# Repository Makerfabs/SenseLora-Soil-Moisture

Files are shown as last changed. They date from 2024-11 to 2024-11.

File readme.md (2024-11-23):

SenseLora Soil Moisture
```c++
/*
Version:	    V1.0
Author:		    Yuki
Create Date:	2024/11/20
Note:
*/
```

# Makerfabs

[Makerfabs home page](https://www.makerfabs.com/)

[Makerfabs Wiki](https://wiki.makerfabs.com/)

## Intruduce

Product Link:[SenseLora Soil Moisture](https://www.makerfabs.com/senselora-soil-moisture.html)

Wiki Link : [SenseLora Soil Moisture](https://wiki.makerfabs.com/SenseLora_Soil_Moisture.html)

## Features

Specs:
- ESP32-S3 WROOM module onboard with the WiFi and Bluetooth.
- Detection of soil moisture.
- Arduino Compatible: You can play it with Arduino IDE.
- Onboard LoRa module (433Mhz or 868Mhz or 915Mhz)
- Completely sealed.
- Dustproof waterproof level:IP68.
- Power by 3.7V battery.
- On board MPTT battery charger by solar panel.

# Usage

1.[Usage with LoRa Receiver](https://wiki.makerfabs.com/SenseLora_Soil_Moisture.html#4-usage-with-lora-receiver)

The Lora receiver work with SenseLora modules, it receive LoRa signal around and forward to computer, so the data can be display/record/analyze on PC.

2.[Usage with 4G Gateway](https://wiki.makerfabs.com/SenseLora_Soil_Moisture.html#5-usage-with-4g-gateway)

The 4G LTE CAT1 Gateway work with SenseLora modules, it get the LoRa data and then transmit the data via 4G to cloud server such as TTN, or the monitors phone with SMS.  

## Example

### firmware

Factory test program

### Send data to datacake

Using the Senselora 4G gateway to transfer data to the datacake platform.

### Send data to thingspeak

Using the Senselora 4G gateway to transfer data to the thingspeak platform.

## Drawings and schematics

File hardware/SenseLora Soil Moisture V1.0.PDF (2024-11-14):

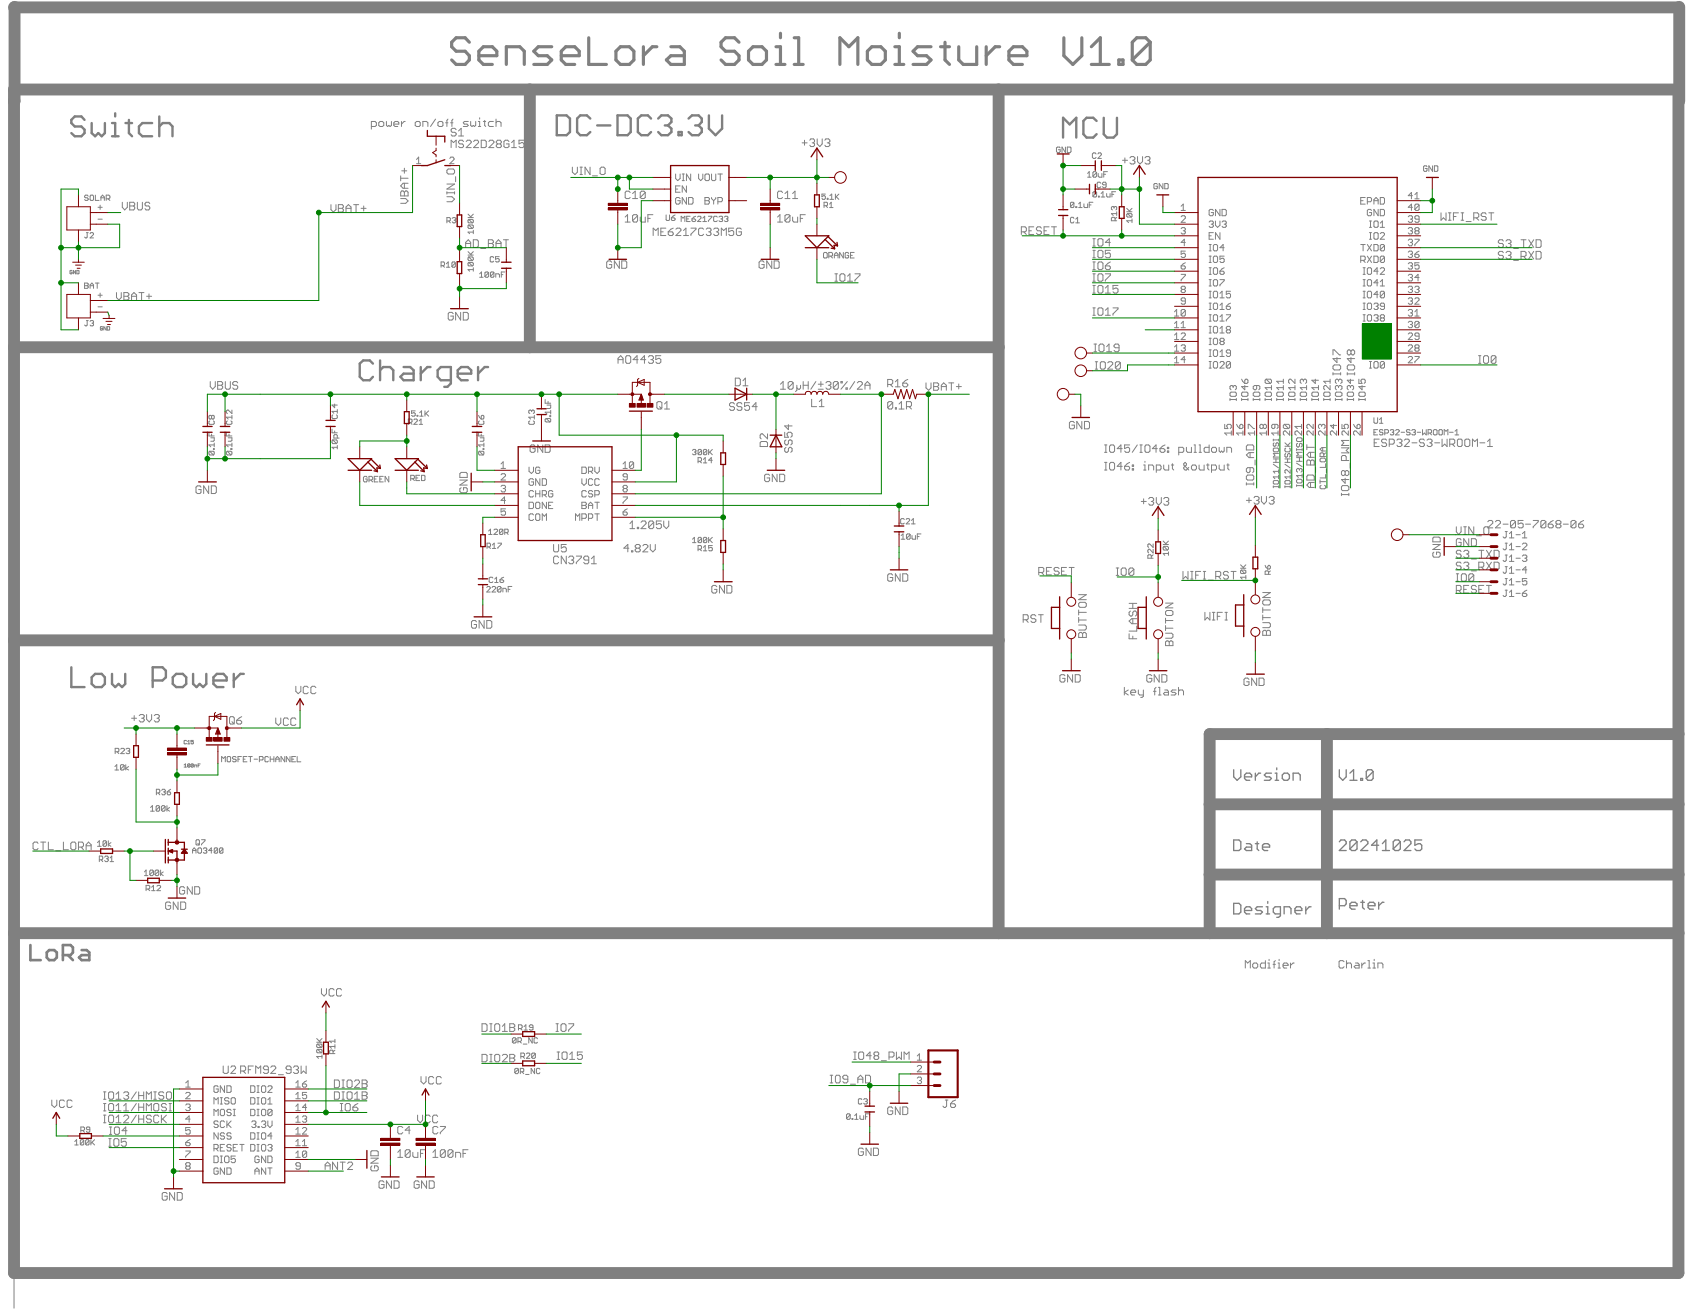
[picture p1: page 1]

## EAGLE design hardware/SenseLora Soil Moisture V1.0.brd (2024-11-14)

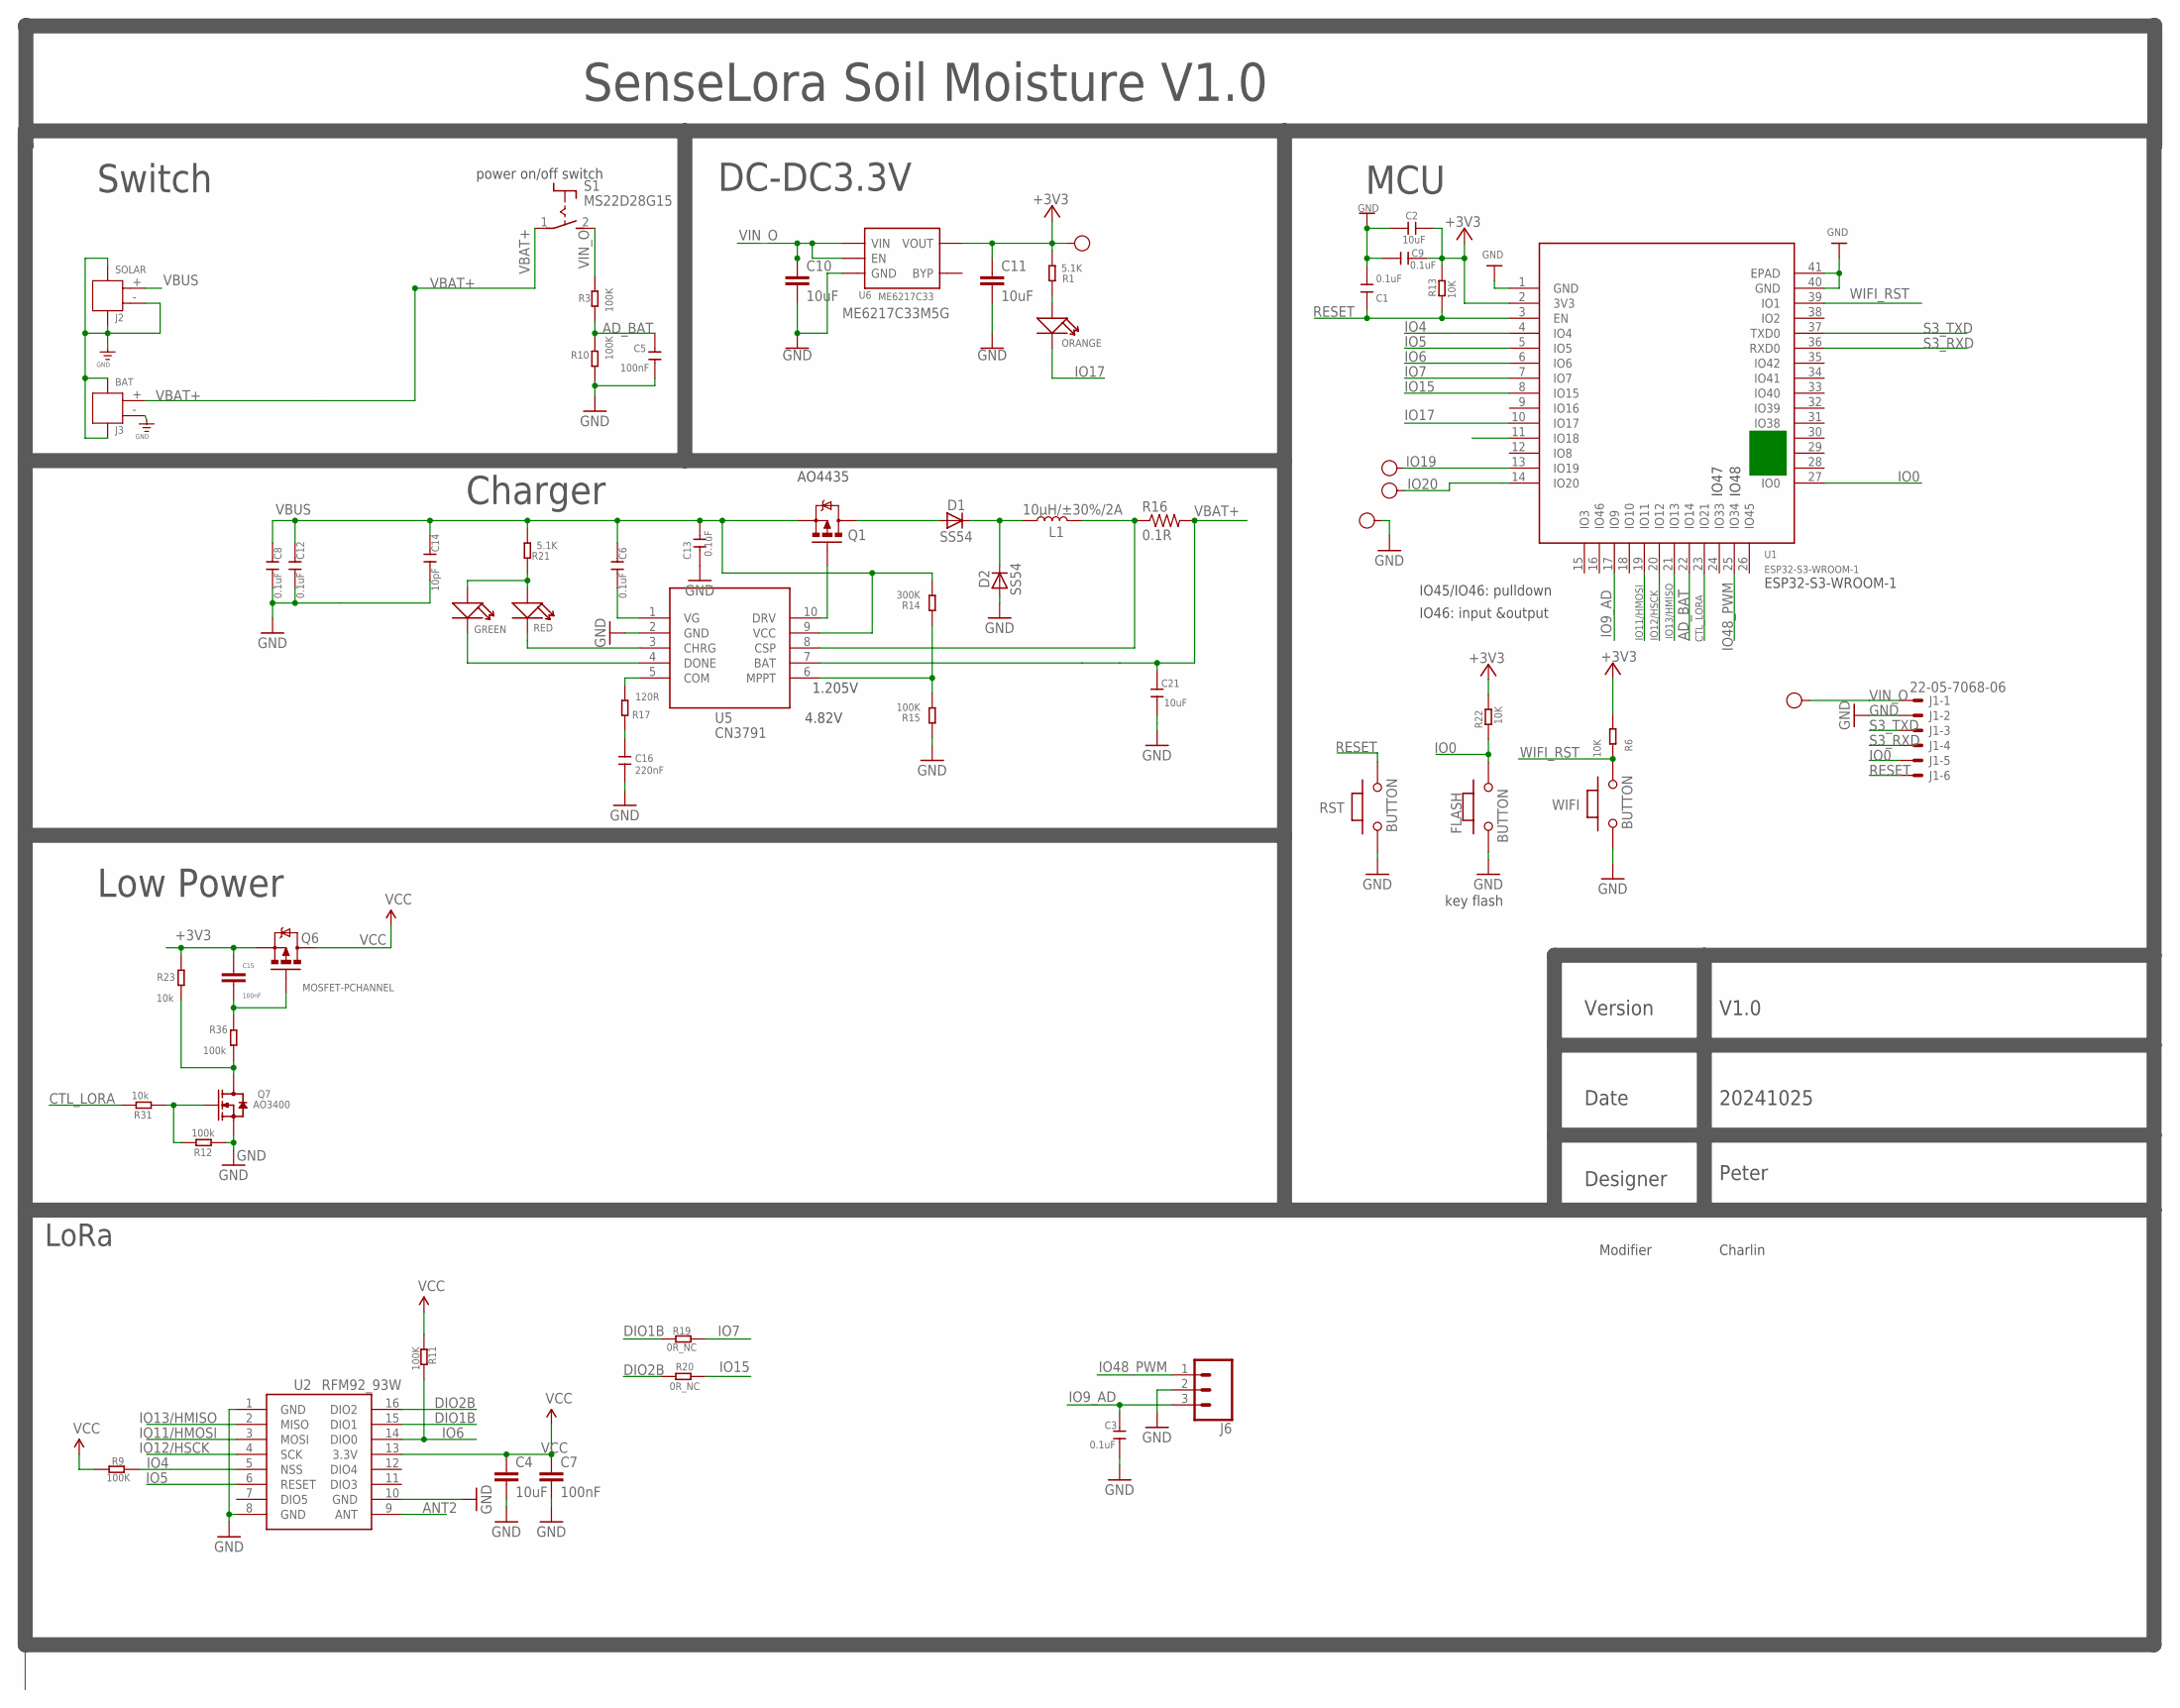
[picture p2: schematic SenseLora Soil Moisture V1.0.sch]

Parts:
3V3: TEST-POINT'4545'; TP-D45MIL; PARTNO DNP
C1, C3, C6, C8, C9, C12, C13: 0.1uF; DISCRETE_C0603
C2, C21: 10uF; DISCRETE_C0603
C4, C10, C11: 10uF; C0603
C5, C7, C15: 100nF; C0603
C14: 10pF; DISCRETE_C0603
C16: 220nF; DISCRETE_C0603
CHRG: RED; LED-0603
D1, D2: SS54; DO-214AC
D+: TEST-POINT'4545'; TP-D45MIL; PARTNO DNP
D-: TEST-POINT'4545'; TP-D45MIL; PARTNO DNP
DONE: GREEN; LED-0603
FLASH: BUTTON; 157SW
GND: TEST-POINT'4545'; TP-D45MIL; PARTNO DNP
J1: 22-05-7068-06; 7395-06
J2: SOLAR; HW2-SMD-2.0-90D
J3: BAT; HW2-SMD-2.0-90D
J6: CONN_03SCREW; SCREWTERMINAL-3.5MM-3
L1: 10µH/±30%/2A; CR54
Q1: MOSFET-PCHANNELFDS6675; SO08
Q6: MOSFET-PCHANNEL; SOT23-3
Q7: AO3400; SOT23@1
R1, R21: 5.1K; DISCRETE_R0603
R3, R9, R10, R11: 100K; R0603
R6, R13, R22: 10K; R0603
R12, R36: 100k; R0603
R14: 300K; DISCRETE_R0603
R15: 100K; DISCRETE_R0603
R16: 0.1R; R1206
R17: 120R; DISCRETE_R0603
R19, R20: 0R_NC; R0603
R23, R31: 10k; R0603
RST: BUTTON; 157SW
S1: MS22D28G15; S-MS22D28G15
STA: ORANGE; LED-0603
U1: ESP32-S3-WROOM-1; ESP32-­S2-­SOLO
U2: RFM92_93W
U5: CN3791; SSOP-10-150MIL
U6: ME6217C33; SOT23-5
VI: HP; TP-D45MIL; PARTNO DNP
WIFI: BUTTON; 157SW

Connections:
+3V3: 3V3.T, C2.1, C9.1, C11.1, C15.1, Q6.2 (S), R1.2, R6.2, R13.2, R22.2, R23.2, U1.2 (3V3), U6.5 (VOUT)
AD_BAT: C5.1, R3.2, R10.1, U1.22 (IO14)
ANT2: U2.9 (ANT)
CTL_LORA: R31.2, U1.23 (IO21)
DIO1B: R19.2, U2.15 (DIO1)
DIO2B: R20.2, U2.16 (DIO2)
GND: C1.2, C2.2, C3.2, C4.2, C5.2, C7.2, C8.2, C9.2, C10.2, C11.2, C12.2, C13.1, C14.2, C16.2, C21.2, D2.A, FLASH.1, GND.T, J1.2, J2.3, J2.4, J2.- (2), J3.3, J3.4, J3.- (2), J6.2, Q7.2 (S), R10.2, R12.1, R15.1, RST.1, U1.1 (GND), U1.40 (GND), U1.41 (EPAD), U2.1 (GND), U2.8 (GND), U2.10 (GND), U5.2 (GND), U6.2 (GND), WIFI.1
IO0: FLASH.2, J1.5, R22.1, U1.27 (IO0)
IO4: R9.1, U1.4 (IO4), U2.5 (NSS)
IO5: U1.5 (IO5), U2.6 (RESET)
IO6: R11.1, U1.6 (IO6), U2.14 (DIO0)
IO7: R19.1, U1.7 (IO7)
IO9_AD: C3.1, J6.3, U1.17 (IO9)
IO11/HMOSI: U1.19 (IO11), U2.3 (MOSI)
IO12/HSCK: U1.20 (IO12), U2.4 (SCK)
IO13/HMISO: U1.21 (IO13), U2.2 (MISO)
IO15: R20.1, U1.8 (IO15)
IO17: STA.-, U1.10 (IO17)
IO19: D-.T, U1.13 (IO19)
IO20: D+.T, U1.14 (IO20)
IO48_PWM: J6.1, U1.25 (IO34)
unnamed: R14.1, R15.2, U5.6 (MPPT)
unnamed: Q1.4 (G), U5.10 (DRV)
unnamed: C6.2, U5.1 (VG)
unnamed: D1.C, D2.C, L1.P$1 (1)
unnamed: D1.A, Q1.5 (D), Q1.6 (D), Q1.7 (D), Q1.8 (D)
unnamed: CHRG.+, DONE.+, R21.1
unnamed: DONE.-, U5.4 (DONE)
unnamed: CHRG.-, U5.3 (CHRG)
unnamed: R17.2, U5.5 (COM)
unnamed: C16.1, R17.1
unnamed: R1.1, STA.+
unnamed: C15.2, Q6.1 (G), R36.2
unnamed: Q7.1 (G), R12.2, R31.1
unnamed: L1.P$2 (2), R16.1, U5.8 (CSP)
unnamed: Q7.3 (D), R23.1, R36.1
RESET: C1.1, J1.6, R13.1, RST.2, U1.3 (EN)
S3_RXD: J1.4, U1.36 (RXD0)
S3_TXD: J1.3, U1.37 (TXD0)
VBAT+: C21.1, J3.+ (1), R16.2, S1.1, U5.7 (BAT)
VBUS: C6.1, C8.1, C12.1, C13.2, C14.1, J2.+ (1), Q1.1 (S), Q1.2 (S), Q1.3 (S), R14.2, R21.2, U5.9 (VCC)
VCC: C4.1, C7.1, Q6.3 (D), R9.2, R11.2, U2.13 (3.3V)
VIN_O: C10.1, J1.1, R3.1, S1.2 (S), U6.1 (VIN), U6.3 (EN), VI.T
WIFI_RST: R6.1, U1.39 (IO1), WIFI.2

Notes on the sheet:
DC-DC3.3V
ME6217C33M5G
Charger
LoRa
power on/off switch
key flash
Switch
MCU
Low Power
IO45/IO46: pulldown
IO46: input &output
ESP32-S3-WROOM-1
IO47
IO48
Version
Date
Designer
V1.0
20241025
Peter
SenseLora Soil Moisture V1.0
1.205V
4.82V
Modifier
Charlin
AO4435

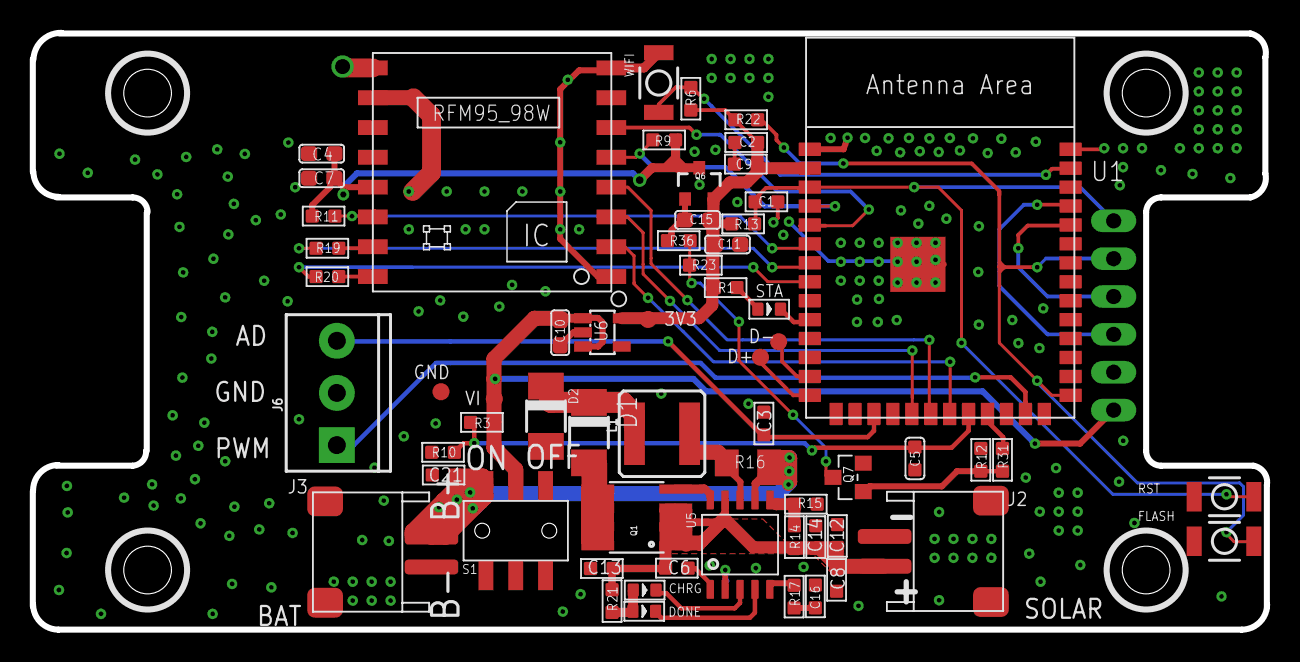
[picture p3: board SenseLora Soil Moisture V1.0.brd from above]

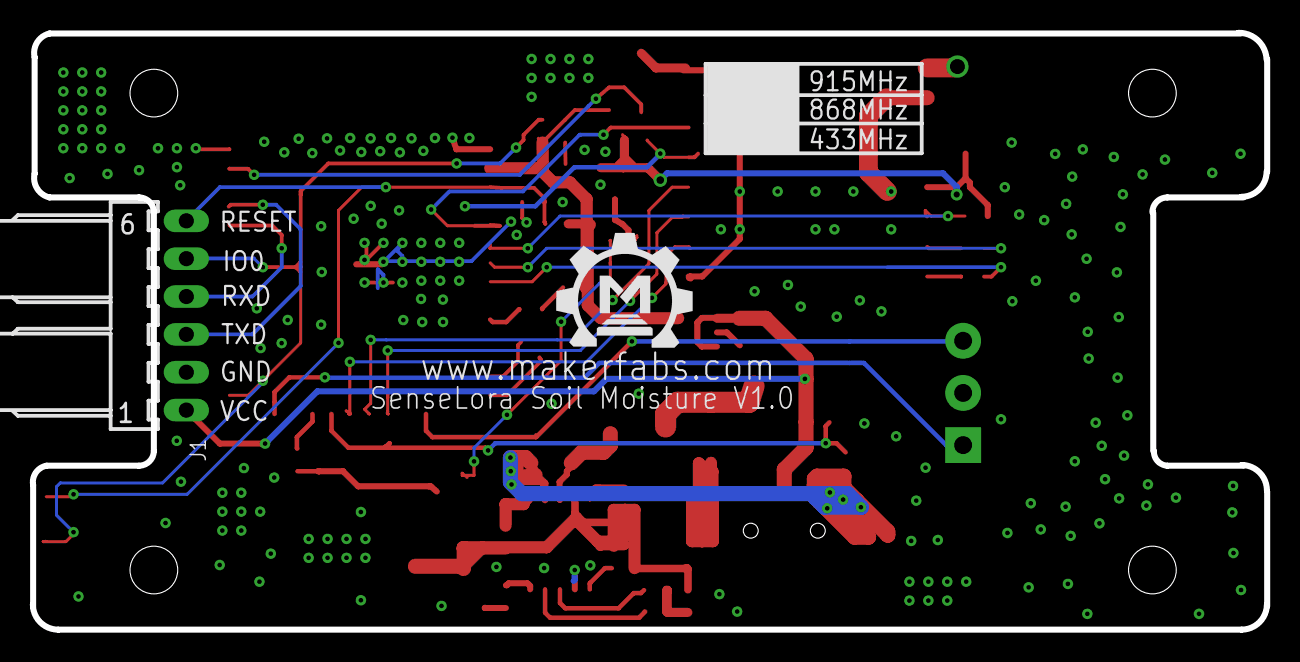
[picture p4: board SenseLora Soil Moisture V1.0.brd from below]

Board: 2 copper layers, 82.8 x 40.0 mm, 63 parts (2 on the bottom side), 43 nets.

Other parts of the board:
U$3: MAKERFABS_0.3

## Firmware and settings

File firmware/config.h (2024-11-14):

#ifndef CONFIG_H
#define CONFIG_H

#define AP_SSID "Makerfabs-"
#define AP_PWD "12345678"

#define DEFAULT_SENSOR_ID "SoilM01"
#define DEFAULT_SLEEP_TIME "3600"

#define SUCCESS 1
#define ERROR 0

#define NVS_DATA_LENGTH 20

#define uS_TO_S_FACTOR 1000000ULL /* Conversion factor for micro seconds to seconds */

#define BUTTON_PIN 1
#define BAT_PIN 14

// Lora
#define LORA_RST 5
#define LORA_CS 4

#define DIO0 6
#define DIO1 7

#define SPI_MOSI 11
#define SPI_MISO 13
#define SPI_SCK 12

#define FREQUENCY 868.0
#define BANDWIDTH 125.0
#define SPREADING_FACTOR 12
#define CODING_RATE 6
#define OUTPUT_POWER 20
#define PREAMBLE_LEN 8
#define GAIN 0


// Power Control
#define POWER_LORA 21

#define I2S_DOUT  47
#define I2S_BCLK  48
#define I2S_LRC   45

#define  sensorADCPin 9

#endif

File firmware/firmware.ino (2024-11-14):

// 使用 4.6.0  版本的库 RadioLib 在文件夹： C:\Users\maker\Documents\Arduino\libraries\RadioLib
// 使用 2.0.0  版本的库 SPI 在文件夹： C:\Users\maker\AppData\Local\Arduino15\packages\esp32\hardware\esp32\2.0.14\libraries\SPI
// 使用 2.0.0  版本的库 WiFi 在文件夹： C:\Users\maker\AppData\Local\Arduino15\packages\esp32\hardware\esp32\2.0.14\libraries\WiFi

#include <RadioLib.h> //LORA库
#include <SPI.h>

#include "Arduino.h"
#include "WiFiMulti.h"
#include "driver/i2s.h"
#include "config.h"
#include "web_server.h"

SX1276 radio = new Module(LORA_CS, DIO0, LORA_RST, DIO1, SPI, SPISettings());


// Sensor Config
char sensor_id[NVS_DATA_LENGTH];
char sleep_time[NVS_DATA_LENGTH];

int count=0;

unsigned char resp[80] = {0};

float analogValue = 0.0;
//float analogVolts = 0.0;
float bat_vol = 0.0;

RTC_DATA_ATTR int bootCount = 0;

void setup()
{
    pin_init();

    Serial.begin(115200);

    ++bootCount;
    Serial.println("Boot number: " + String(bootCount));
    print_wakeup_reason();

    SPI.begin(SPI_SCK, SPI_MISO, SPI_MOSI);
    lora_init();
    I2S_INIT();
    analogReadResolution(12); //设置ADC分辨率为12位，输入电压映射到0-4095的值
    // Button Check
    read_bat();
    wifi_init();
    delay(5000);
}

void loop()
{
    // Send three time and sleep
    for (int i = 0; i < 15; i++)
    {
        // Serial.println(lora_msg_create());

        // String temp = "";

        // temp = sensor_read();
        sensor_read();
        read_bat();
        value_log();
        if (i > 13)
        {
            // temp = lora_msg_create(temp);
            // lora_send_task(temp);
            check_count(&count);
            record_count(++count);
            lora_send_task(json_create());
        }

        delay(2000);
    }

    int sleep_s = atoi(sleep_time); //将数组转化为整数值
    esp_sleep_enable_timer_wakeup(sleep_s * uS_TO_S_FACTOR); //设置睡眠模式为时间唤醒
    Serial.println("Setup ESP32 to sleep for every " + String(sleep_s) + " Seconds");

    // esp_sleep_enable_timer_wakeup(TIME_TO_SLEEP * uS_TO_S_FACTOR);
    // Serial.println("Setup ESP32 to sleep for every " + String(TIME_TO_SLEEP) + " Seconds");
    
    Serial.println("Going to sleep now");
    Serial.flush();//确保深度睡眠时数据发送完毕
    esp_deep_sleep_start();
    Serial.println("This will never be printed");
}

// Hardware init

void pin_init()
{
    pinMode(POWER_LORA, OUTPUT);
    pinMode(LORA_CS, OUTPUT);
    pinMode(BAT_PIN, INPUT);
    digitalWrite(POWER_LORA, HIGH);
    delay(100);
}


void lora_init()
{
    Serial.print(F("[SX1276] Initializing ... "));

    int state = radio.begin(FREQUENCY, BANDWIDTH, SPREADING_FACTOR, CODING_RATE, SX127X_SYNC_WORD, OUTPUT_POWER, PREAMBLE_LEN, GAIN);
    if (state == ERR_NONE)
    {
        Serial.println(F("success!"));
    }
    else
    {
        Serial.print(F("failed, code "));
        Serial.println(state);
        while (true)
            ;
    }
}

// Lora send task
String lora_msg_create(String sensor_data)
{
    String temp = "ID:";
    temp = temp + sensor_id + ",SLEEP:" + sleep_time + "," + sensor_data;

    return temp;
}

String json_create()
{
    String temp = "{";
    temp = temp + "\"ID\":\"" + sensor_id + "\",\"COUNT\":" + count + ",\"SLEEP\":" + sleep_time + ",";
    temp = temp + "\"bat\":" + bat_vol + ",";
    temp = temp + "\"ADC\":" + analogValue + "}";
    //temp = temp + "\"ADC_millivolts_value\":" + analogVolts + "}";

    return temp;
}

void lora_send_task(String data)
{
    Serial.println(data);
    int state = radio.transmit(data.c_str());
    if (state == ERR_NONE)
    {
        // the packet was successfully transmitted
        Serial.println(F(" success!"));

        // print measured data rate
        Serial.print(F("[SX1276] Datarate:\t"));
        Serial.print(radio.getDataRate());
        Serial.println(F(" bps"));
    }
    else if (state == ERR_PACKET_TOO_LONG)
    {
        // the supplied packet was longer than 256 bytes
        Serial.println(F("too long!"));
    }
    else if (state == ERR_TX_TIMEOUT)
    {
        // timeout occurred while transmitting packet
        Serial.println(F("timeout!"));
    }
    else
    {
        // some other error occurred
        Serial.print(F("failed, code "));
        Serial.println(state);
    }
}

// Soil Sensor
String sensor_read()
{
    analogValue = analogRead(sensorADCPin);
    //analogVolts = analogReadMilliVolts(sensorADCPin);

    String str = "ADC_analog_value:";
    str = str + analogValue;
    //str = str + analogValue + ",ADC_millivolts_value:" + analogVolts;

    return str;
}


void value_log()
{
    Serial.print("ADC: ");
    Serial.println(analogValue);
    //Serial.print("ADC millivolts value =");
    //Serial.println(analogVolts);
    Serial.print("Bat: ");
    Serial.print(bat_vol);
    Serial.println(" V");
}

int CaculateValue(int x, int y)
{
    int t = 0;
    t = x * 256;
    t = t + y;
    return t;
}

void print_wakeup_reason()
{
    esp_sleep_wakeup_cause_t wakeup_reason;

    wakeup_reason = esp_sleep_get_wakeup_cause();

    switch (wakeup_reason)
    {
    case ESP_SLEEP_WAKEUP_EXT0:
        Serial.println("Wakeup caused by external signal using RTC_IO");
        break;
    case ESP_SLEEP_WAKEUP_EXT1:
        Serial.println("Wakeup caused by external signal using RTC_CNTL");
        break;
    case ESP_SLEEP_WAKEUP_TIMER:
        Serial.println("Wakeup caused by timer");
        break;
    case ESP_SLEEP_WAKEUP_TOUCHPAD:
        Serial.println("Wakeup caused by touchpad");
        break;
    case ESP_SLEEP_WAKEUP_ULP:
        Serial.println("Wakeup caused by ULP program");
        break;
    default:
        Serial.printf("Wakeup was not caused by deep sleep: %d\n", wakeup_reason);
        break;
    }
}

float c2f(float c_temp)
{
    return c_temp * 9.0 / 5.0 + 32;
}

void read_bat()
{
    bat_vol = 3.3 * analogRead(BAT_PIN) / 4096 * 2;
}

void I2S_INIT(void) 
{
    //i2s configuration
    uint8_t m_i2s_num = I2S_NUM_0; // i2s port number
    i2s_config_t i2s_config = {
         .mode = (i2s_mode_t)(I2S_MODE_MASTER | I2S_MODE_TX),
         .sample_rate = 48000,
         .bits_per_sample = I2S_BITS_PER_SAMPLE_16BIT,//I2S_BITS_PER_SAMPLE_16BIT,//
         .channel_format = I2S_CHANNEL_FMT_RIGHT_LEFT,
         .communication_format = (i2s_comm_format_t)(I2S_COMM_FORMAT_I2S | I2S_COMM_FORMAT_I2S_MSB),
         .intr_alloc_flags = ESP_INTR_FLAG_LEVEL1, // high interrupt priority
         .dma_buf_count = 8,  // max buffers
         .dma_buf_len = 1024, // max value
         .use_apll = 0,//APLL_DISABLE,
         .tx_desc_auto_clear= true,  // new in V1.0.1
         .fixed_mclk=-1
    };
    i2s_driver_install((i2s_port_t)m_i2s_num, &i2s_config, 0, NULL);
    
    i2s_pin_config_t pins = {
      .bck_io_num = I2S_BCLK,           // Bit Clock
      .ws_io_num =  I2S_LRC,            //  wclk,// Left/Right Clock
      .data_out_num = I2S_DOUT,         // Data Out
      .data_in_num = -1
    };
    i2s_set_pin((i2s_port_t)m_i2s_num, &pins);
}

esp_err_t I2Sstart(uint8_t i2s_num) {
    return i2s_start((i2s_port_t) i2s_num);
}

esp_err_t I2Sstop(uint8_t i2s_num) {
    return i2s_stop((i2s_port_t) i2s_num);
}

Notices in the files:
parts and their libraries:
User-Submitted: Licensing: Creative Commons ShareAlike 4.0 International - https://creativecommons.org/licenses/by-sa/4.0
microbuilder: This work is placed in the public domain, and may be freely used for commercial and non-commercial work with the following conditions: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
